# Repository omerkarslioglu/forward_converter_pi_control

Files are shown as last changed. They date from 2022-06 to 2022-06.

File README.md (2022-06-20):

# Forwar Converter With PI Controller
9-36V Input Voltage, 28 Output Voltage, All Ripple: %2, 50KHz, 50 Watt DC-DC Forward Converter Design And Production

The aim of the project is to design and produce a dc-dc forward converter according to following
requirements:
Vin: 36-9 V,
Vout: 28 V,
Power: 50 Watt,
Ripple Ratings: 2%,
Fsw : 50 KHz,
Control System: PI with a STM32F4 MCU.
In addition to this, this paper shows formulas, calculations, experimental and simulation results of dc-dc
forward converter.

# Forward Converter
A forward converter is a switched-mode power supply (SMPS) circuit that transfers energy to
secondary side from primary side and ensures to decrease secondary side input voltage. Forward
converter circuit is similar to the fly-back converter circuit but it is more efficient than fly-back
converter circuit. Forward converter is mainly used for the application which requires higher power
output.
Secondary side of forward converter basicly derives from buck converter. But forward converter can
increase or decrease the input voltage thanks to transformer.
Forward converter is an isolated circuit as it has transformer.



As per the above block diagram, when the switch is turned ON, the input is applied to the primary
winding of the transformer and a voltage is appeared at the secondary winding of transformer.
Therefore, the dot polarity of the windings of transformer is positive, due to this the diode D1 gets
forward biased. Then the output voltage of the transformer is fed to the low pass filter circuit which is
connected to the load. When switch is turned OFF, the current in the windings of transformer comes
down to zero (assuming the transformer to be ideal).
A typical forward converter consists of a:
 Transformer which is either a step-up or step-down with a single or multiple secondary
windings. The type used depends on the available input voltage and desired output voltage. It
also provides isolation of the load from the input voltage.
- Switching components
- Diodes
- Capacitors
- Inductor

# Circuit Design For Simulation On Simulink


The all calculations, values and simulations result in the report.

# Circuit Schematic


# PCB Design



# About Software
As it is known, this designed circuit is designed as a close loop system and will be controlled by
PI. The software of this circuit works as follows: voltage is read with ADC and required ratio
calculation is made. This calculated value enters the PI algorithm and is compared with the
setpoint. If this value is not the same as the setpoint, the PI calculates a new value close to or the
same as the setpoint. This value is again proportioned and the PWM signal driving the mosfet is
updated again.


The closed loop system of Forward Converter is as above diagram. It is PID system. But Kd equals 0
as seting PI.
The software generally consists of two or three main modules:
1. main.c : It is the file where all the configurations are found, the main algorithm and PWM are
set.
2. ADC_READ.c : It is an analog reading value module that I developed specially for the
STM32F4 discovery board.
3. PID.c : It is the module where I wrote the PID algorithm.
Other folders belong to the HAL Library used and the processor's drivers.



All necessary explanations are in the software modules in the software folder in the project file.

Product:
WhatsApp Image 2022-06-20 at 11 33 35
WhatsApp Image 2022-06-20 at 11 33 34

If you have any question, you can contact me.

Omer Karslioglu
omerkarsliogluu@gmail.com

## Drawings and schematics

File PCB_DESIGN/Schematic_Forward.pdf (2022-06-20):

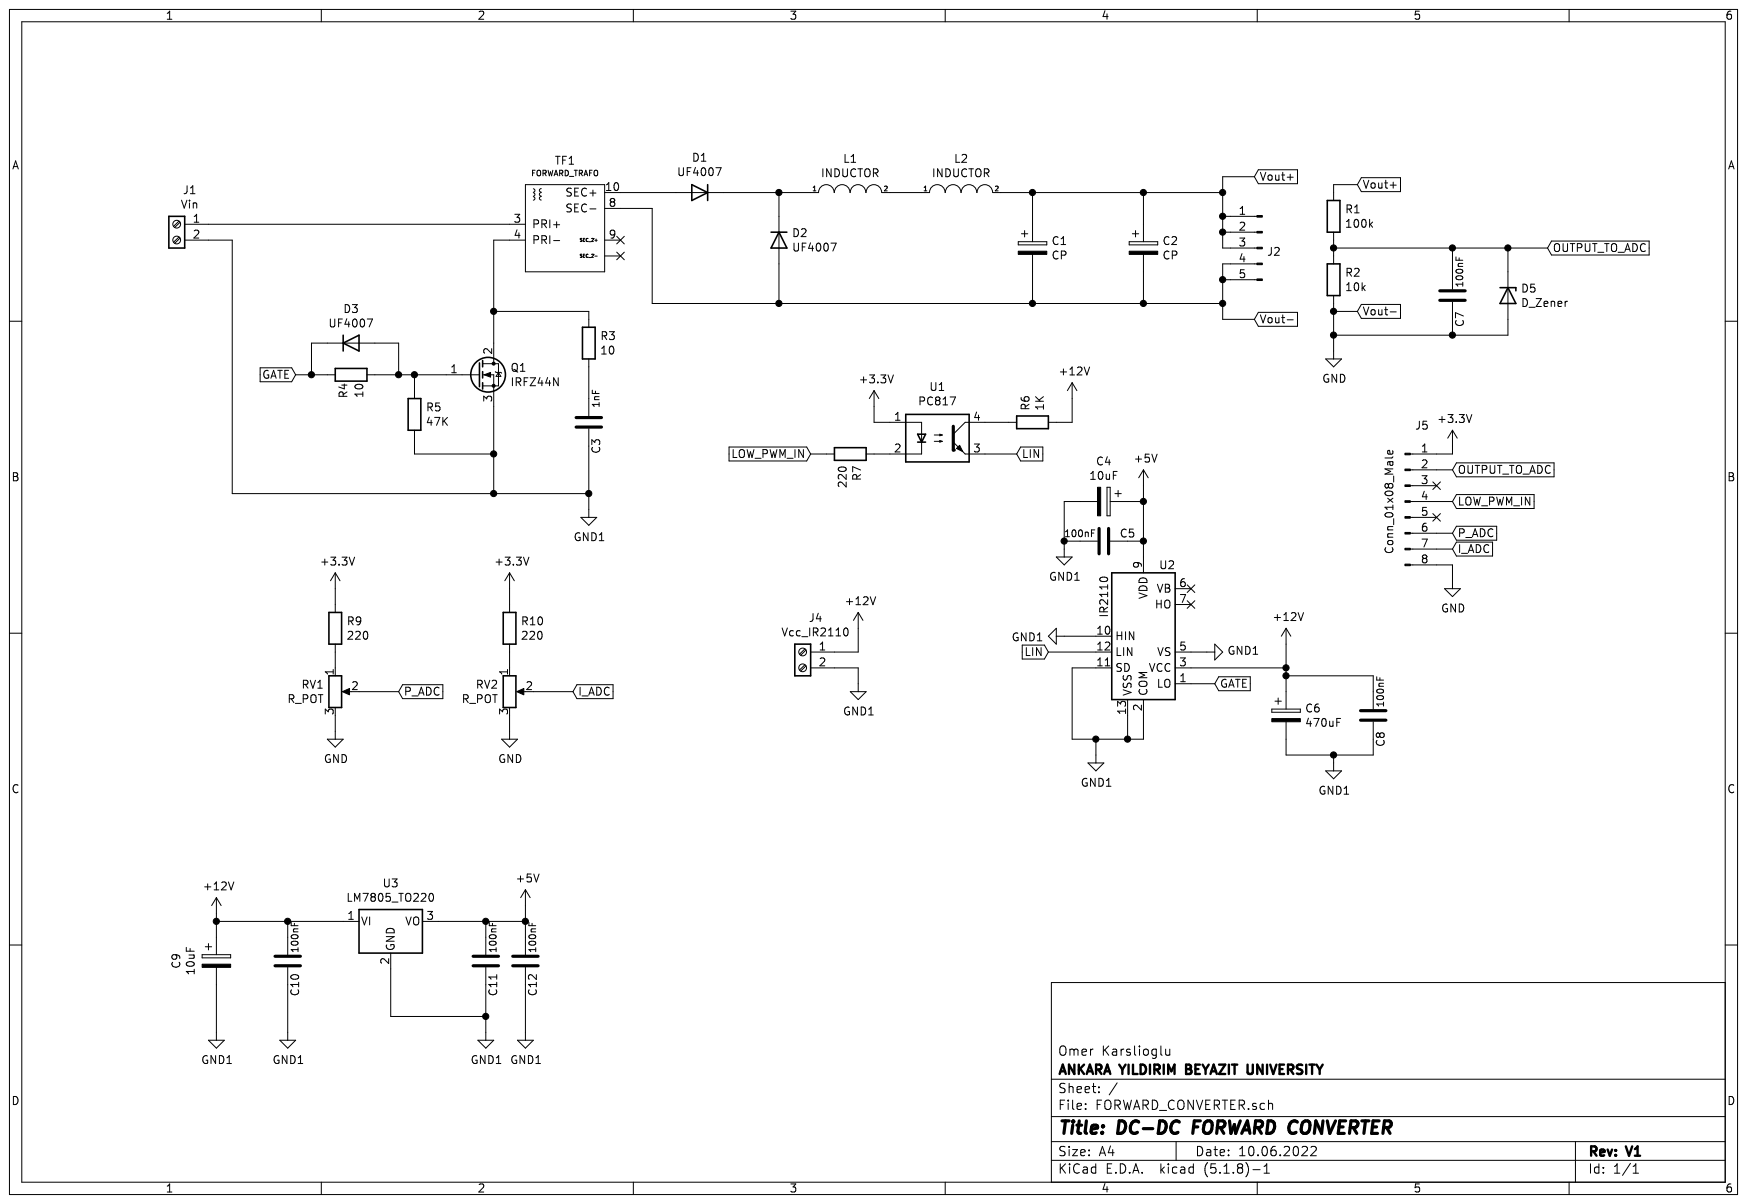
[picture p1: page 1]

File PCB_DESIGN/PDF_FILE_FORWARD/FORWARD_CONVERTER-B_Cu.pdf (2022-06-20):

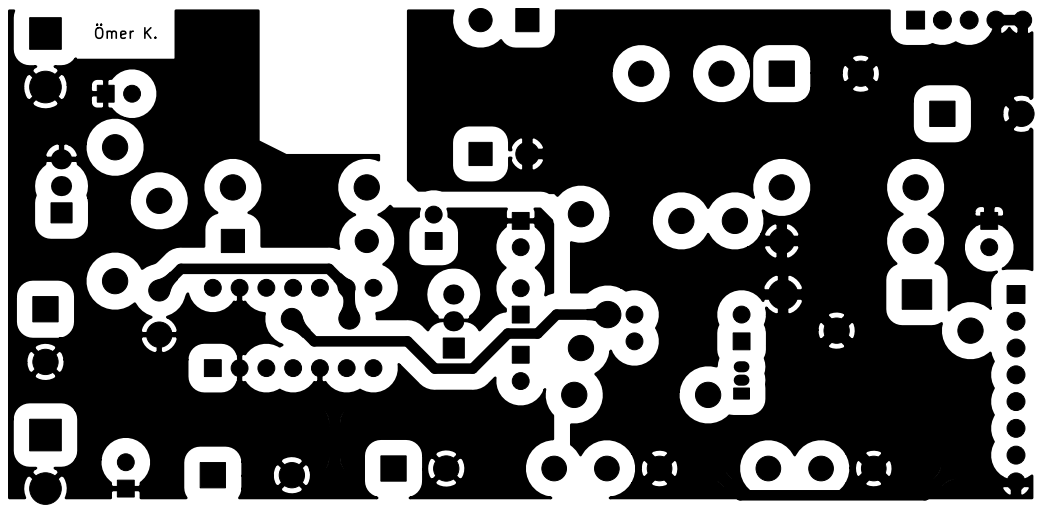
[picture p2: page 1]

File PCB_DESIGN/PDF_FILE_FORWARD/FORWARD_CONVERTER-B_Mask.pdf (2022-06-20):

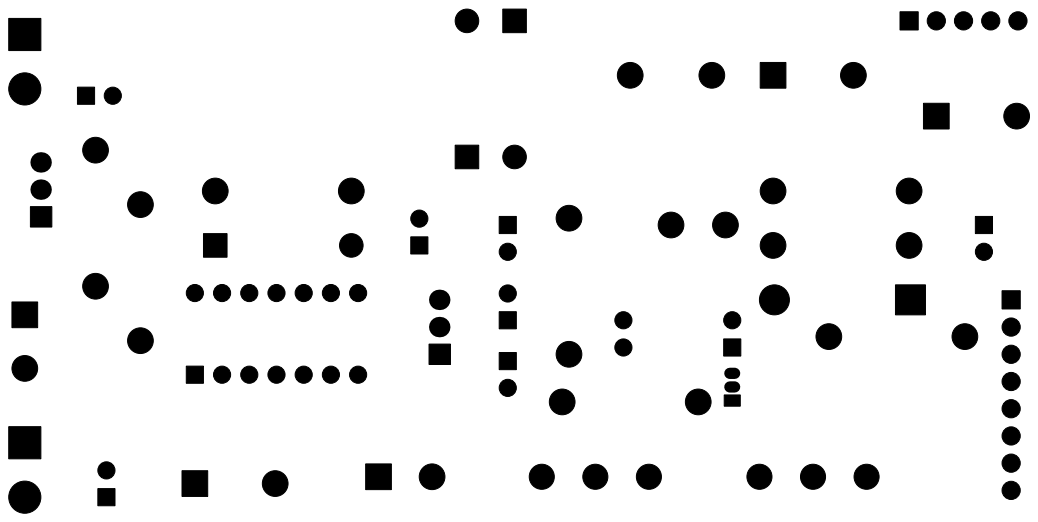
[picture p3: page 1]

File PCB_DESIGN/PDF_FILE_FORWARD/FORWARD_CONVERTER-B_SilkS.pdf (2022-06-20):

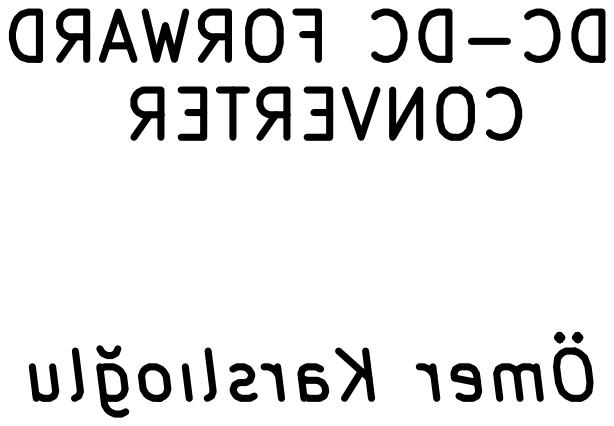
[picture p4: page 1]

Ömer Karslolu DC-DC FORWARD

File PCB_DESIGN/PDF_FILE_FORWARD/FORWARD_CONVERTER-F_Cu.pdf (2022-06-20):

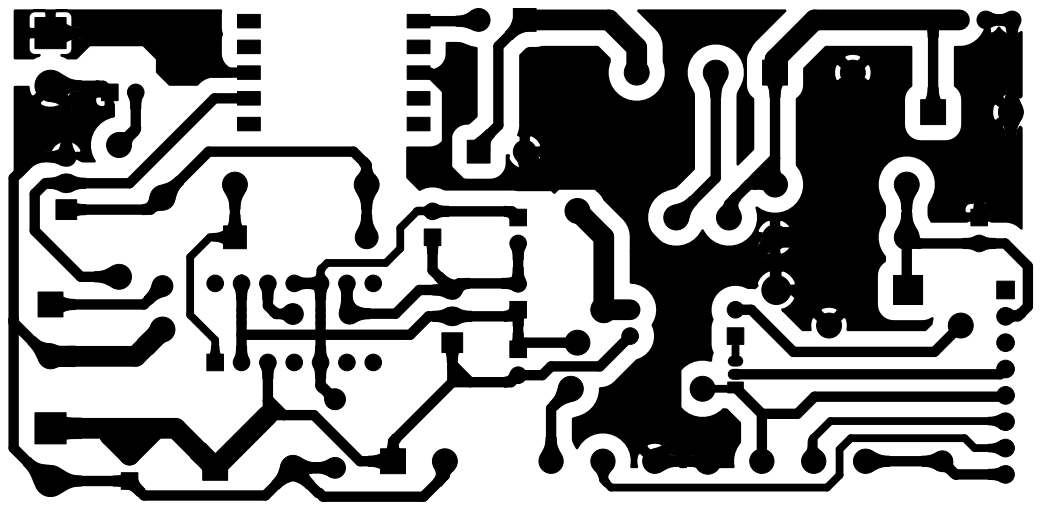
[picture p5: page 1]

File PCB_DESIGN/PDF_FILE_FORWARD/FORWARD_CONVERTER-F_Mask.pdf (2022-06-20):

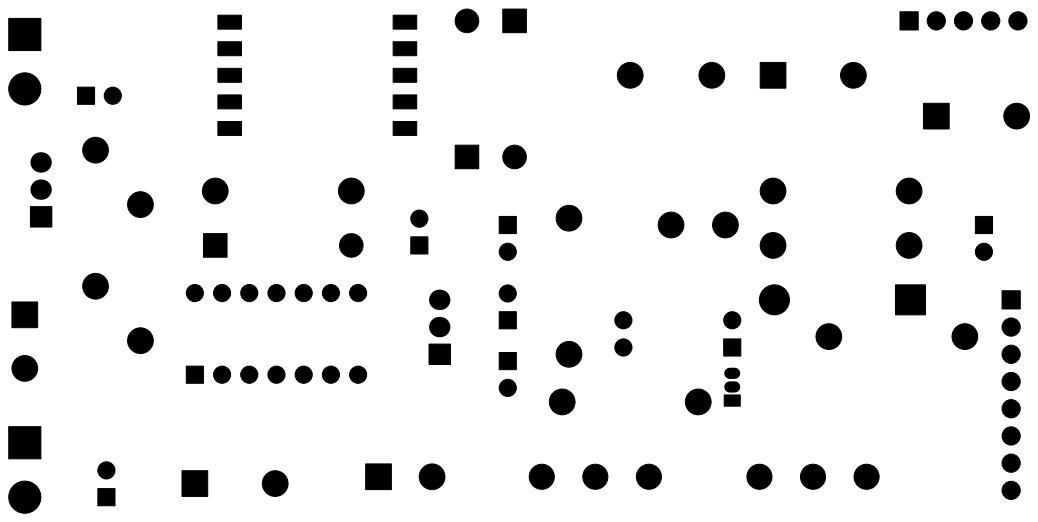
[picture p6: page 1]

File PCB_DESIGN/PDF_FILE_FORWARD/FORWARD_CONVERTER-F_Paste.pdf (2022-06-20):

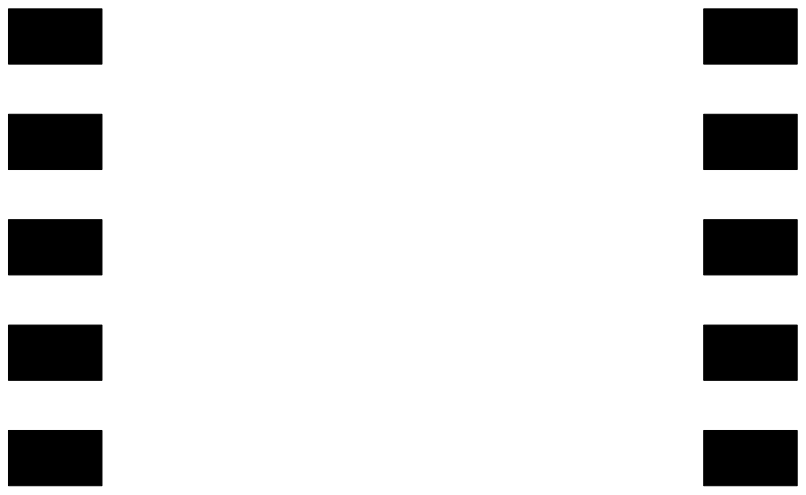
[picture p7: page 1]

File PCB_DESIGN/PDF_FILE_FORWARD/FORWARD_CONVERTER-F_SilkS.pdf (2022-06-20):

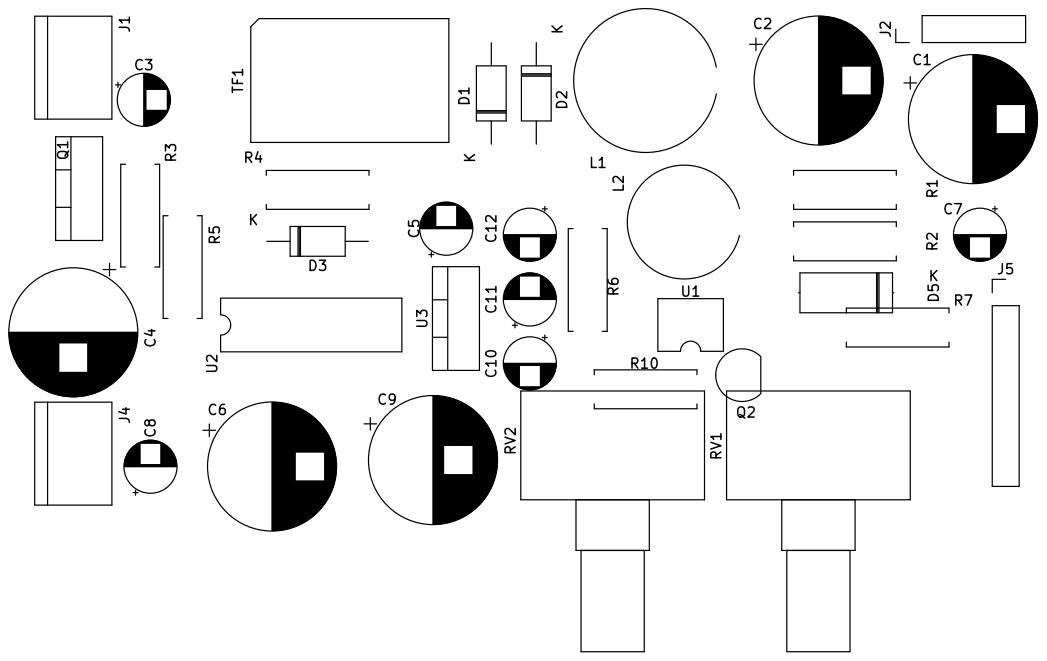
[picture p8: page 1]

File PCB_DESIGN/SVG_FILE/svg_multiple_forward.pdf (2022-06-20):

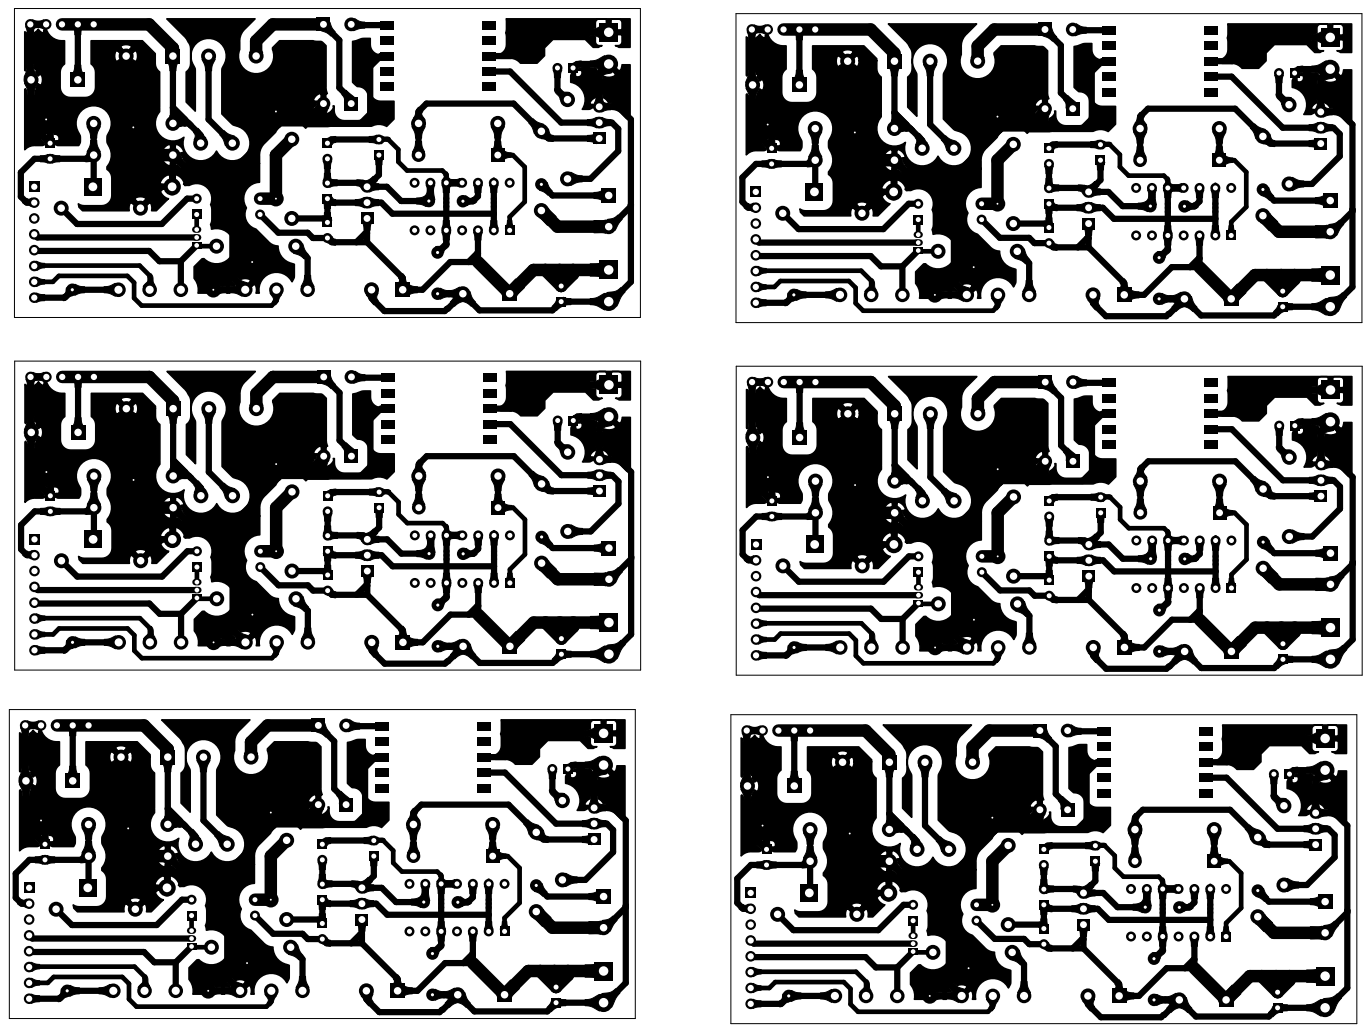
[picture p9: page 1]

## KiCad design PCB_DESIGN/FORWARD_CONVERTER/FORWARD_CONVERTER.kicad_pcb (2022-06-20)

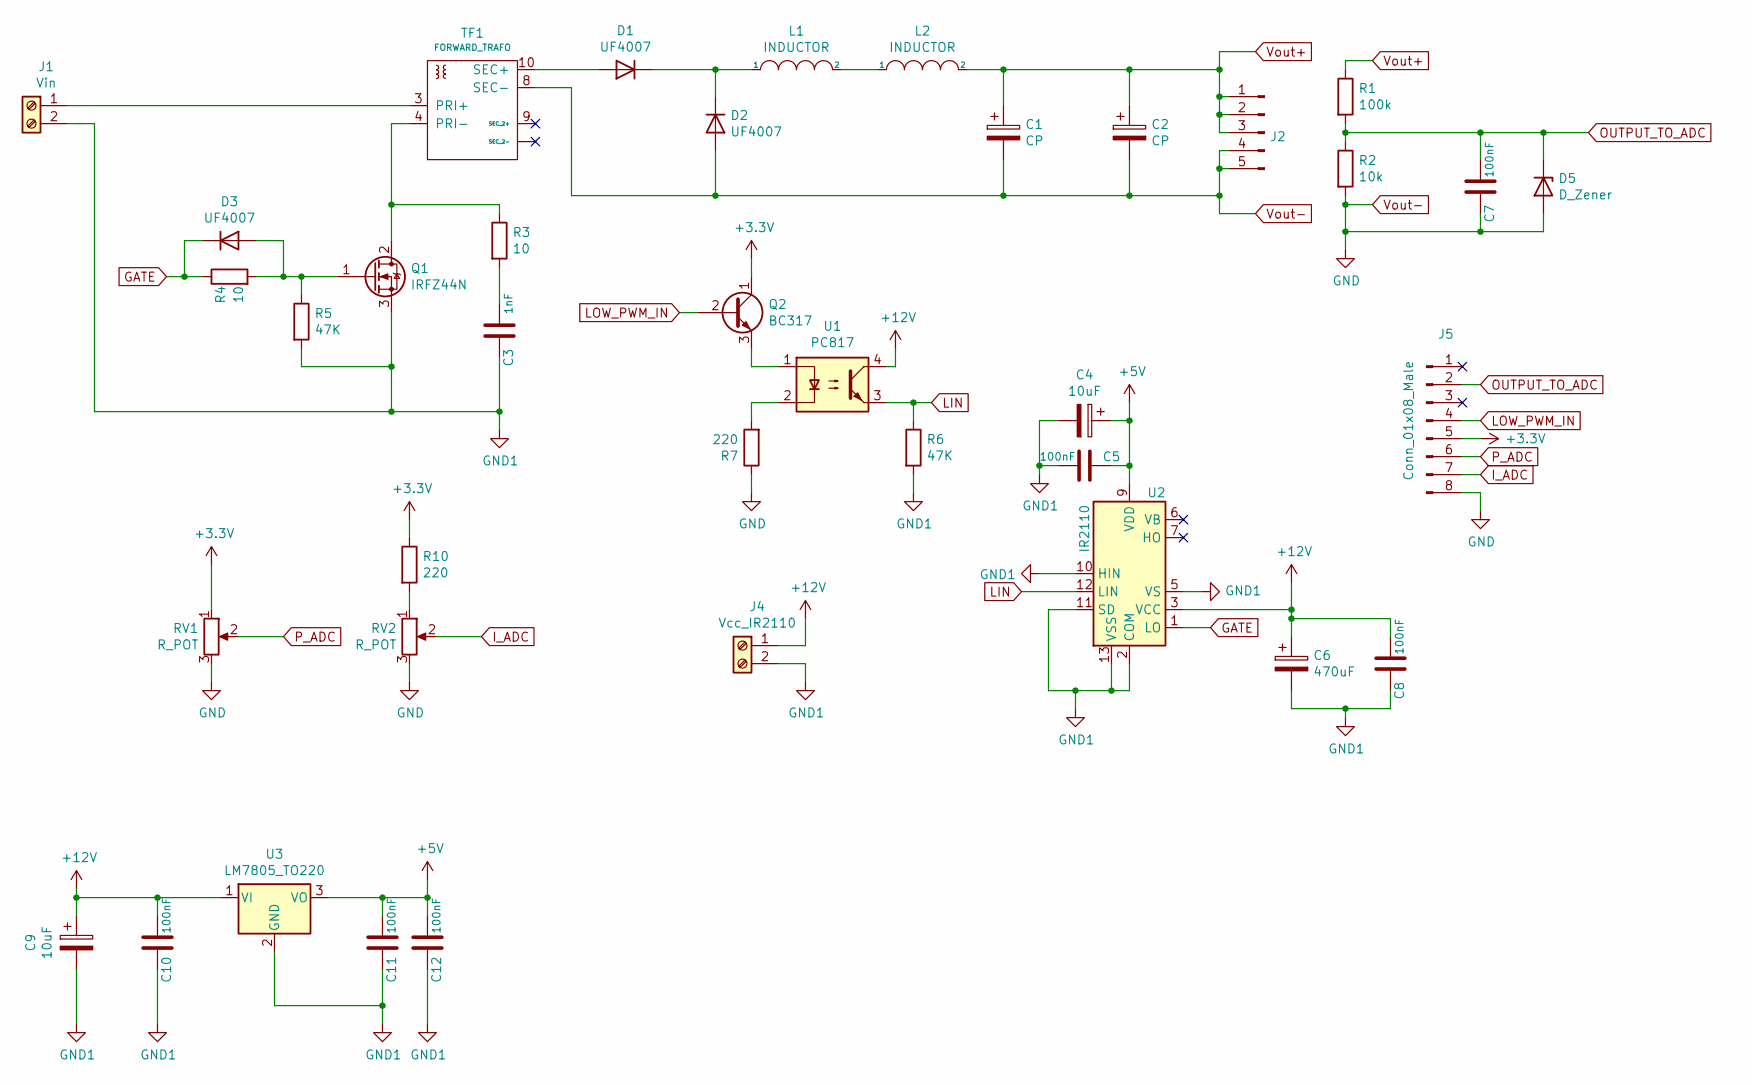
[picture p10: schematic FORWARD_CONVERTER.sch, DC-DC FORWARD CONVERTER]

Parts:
C1, C2: CP; CP_Radial_D12.5mm_P7.50mm
C3: 1nF; CP_Radial_D5.0mm_P2.50mm
C4, C9: 10uF; CP_Radial_D12.5mm_P5.00mm
C5, C7, C8, C10, C11, C12: 100nF; CP_Radial_D5.0mm_P2.50mm
C6: 470uF; CP_Radial_D12.5mm_P7.50mm
D1, D2, D3: UF4007; D_DO-41_SOD81_P12.70mm_Horizontal
D5: D_Zener; D_5W_P12.70mm_Horizontal
J1: Vin; TerminalBlock_bornier-2_P5.08mm
J2: Conn_01x05_Male; PinHeader_1x05_P2.54mm_Vertical
J4: Vcc_IR2110; TerminalBlock_bornier-2_P5.08mm
J5: Conn_01x08_Male; PinHeader_1x08_P2.54mm_Vertical
L1: INDUCTOR; L_Axial_L26.7mm_D14.0mm_P7.62mm_Vertical_Vishay_IHA-104
L2: INDUCTOR; L_Axial_L26.0mm_D11.0mm_P5.08mm_Vertical_Fastron_77A
Q1: IRFZ44N; TO-220-3_Vertical
Q2: BC317; TO-92_Inline
R1: 100k; R_Axial_DIN0411_L9.9mm_D3.6mm_P12.70mm_Horizontal
R2: 10k; R_Axial_DIN0411_L9.9mm_D3.6mm_P12.70mm_Horizontal
R3, R4: 10; R_Axial_DIN0411_L9.9mm_D3.6mm_P12.70mm_Horizontal
R5, R6: 47K; R_Axial_DIN0411_L9.9mm_D3.6mm_P12.70mm_Horizontal
R7, R10: 220; R_Axial_DIN0411_L9.9mm_D3.6mm_P12.70mm_Horizontal
RV1, RV2: R_POT; Potentiometer_Alps_RK163_Single_Horizontal
TF1: FORWARD_TRAFO
U1: PC817; DIP-4_W10.16mm
U2: IR2110; DIP-14_W7.62mm
U3: LM7805_TO220; TO-220-3_Vertical

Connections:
+3V3: J5.5, Q2.1 (C), R10.1, RV1.1
+5V: C4.1, C5.1, C11.2, C12.2, U2.9 (VDD), U3.3 (VO)
+12V: C6.1, C8.2, C9.1, C10.2, J4.1, U1.4, U2.3 (VCC), U3.1 (VI)
GATE: D3.1 (K), R4.1, U2.1 (LO)
GND1: C3.1, C4.2, C5.2, C6.2, C8.1, C9.2, C10.1, C11.1, C12.1, J1.2, J4.2, Q1.3 (S), R5.2, R6.2, U2.2 (COM), U2.5 (VS), U2.10 (HIN), U2.11 (SD), U2.13 (VSS), U3.2 (GND)
I_ADC: J5.7, RV2.2
LIN: R6.1, U1.3, U2.12 (LIN)
LOW_PWM_IN: J5.4, Q2.2 (B)
unnamed: C3.2, R3.2
unnamed: D1.1 (K), D2.1 (K), L1.1
unnamed: D1.2 (A), TF1.10 (SEC+)
unnamed: D3.2 (A), Q1.1 (G), R4.2, R5.1
unnamed: J1.1, TF1.3 (PRI+)
unnamed: L1.2, L2.1
unnamed: Q1.2 (D), R3.1, TF1.4 (PRI-)
unnamed: Q2.3 (E), U1.1
unnamed: R7.2, U1.2
unnamed: R10.2, RV2.1
OUTPUT_TO_ADC: C7.2, D5.1 (K), J5.2, R1.2, R2.1
P_ADC: J5.6, RV1.2
Vout+: C1.1, C2.1, J2.1, J2.2, J2.3, L2.2, R1.1
Vout-: C1.2, C2.2, C7.1, D2.2 (A), D5.2 (A), J2.4, J2.5, J5.8, R2.2, R7.1, RV1.3, RV2.3, TF1.8 (SEC-)

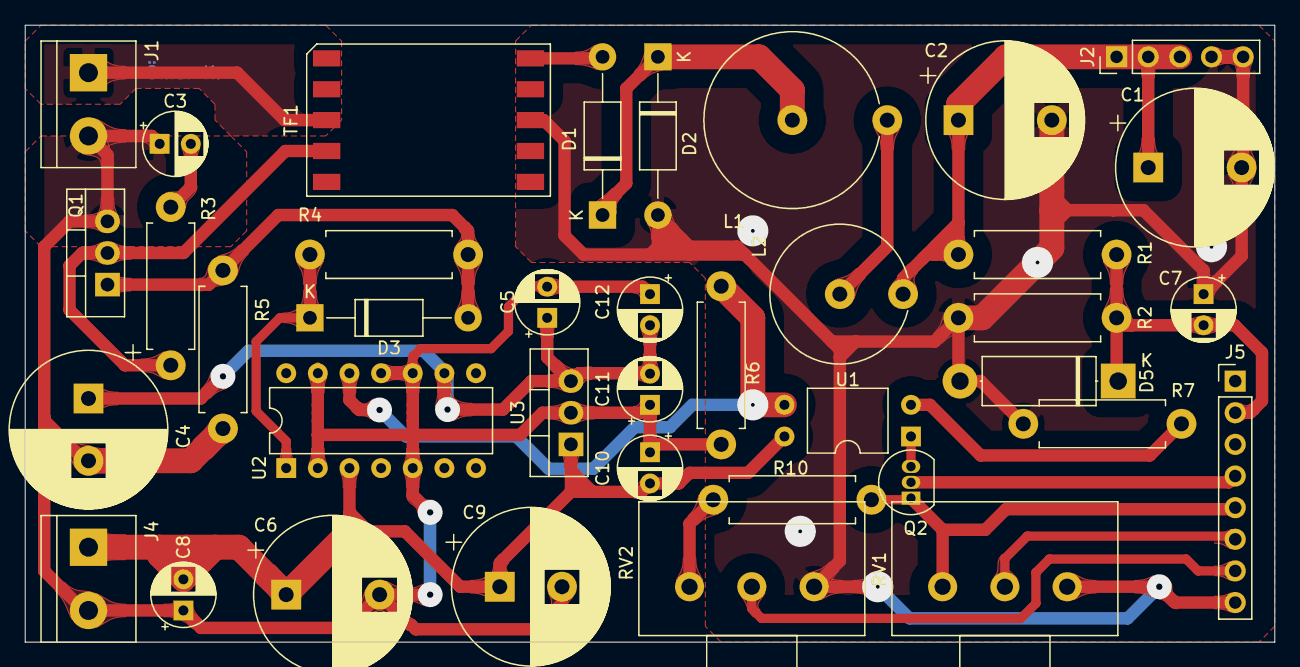
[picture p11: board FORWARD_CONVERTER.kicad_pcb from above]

Board: 2 copper layers, 100.3 x 49.5 mm, 38 parts (0 on the bottom side), 22 nets.

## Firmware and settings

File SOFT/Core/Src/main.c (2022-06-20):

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
/* Includes ------------------------------------------------------------------*/
#include "main.h"

/* USER CODE BEGIN Includes */
#include <stdio.h>
#include <stdlib.h>
#include "ADC_READ.h"
#include "PID.h"
/* USER CODE END Includes */

/* USER CODE BEGIN PD */

#define MIN_PWM_DUTY (float) (7.8  - 4.0)  //(PERCENT RATIO) -> 28/360
#define MAX_PWM_DUTY (float) (31.0 + 4.0)  //(PERCENT RATIO) -> 28/90
#define pwm_resolution (uint16_t) (420-1)
#define adc_resolution (uint16_t) (1024-1)

#define max_lim_integral 10.0f

#define max_lim_PID 30.0f

#define k_p 1.0f
#define k_i 7.0f

/* USER CODE END PD */

ADC_HandleTypeDef hadc1;

TIM_HandleTypeDef htim1;

/* USER CODE BEGIN PV */

uint16_t measurement=0;
float p_constant=0.0;
float i_constant=0.0;

uint16_t min_pwm = 0;
uint16_t max_pwm = 0;
float set_point = 0;

uint16_t 	sim_pwm_out=0;
uint16_t  sim_measurement=0;

uint16_t pwm=0;

float PID_out;
//double kp=0, ki=0, kd=0;
//float pid_p=0, pid_i=0, pid_d=0, PID;
//float error, previousError;
//unsigned long t_now, t_last, dt;

/* USER CODE END PV */

void SystemClock_Config(void);
static void MX_GPIO_Init(void);
static void MX_ADC1_Init(void);
static void MX_TIM1_Init(void);
/**
  * @brief  The application entry point.
  * @retval int
  */
int main(void)
{
  /* USER CODE BEGIN 1 */

	//uint16_t pwm_resolution_int_buff = pwm_resolution;

  /* USER CODE END 1 */

  /* MCU Configuration--------------------------------------------------------*/

  /* Reset of all peripherals, Initializes the Flash interface and the Systick. */
  HAL_Init();

  /* Configure the system clock */
  SystemClock_Config();

  /* Initialize all configured peripherals */
  MX_GPIO_Init();
  MX_ADC1_Init();
  MX_TIM1_Init();
  /* USER CODE BEGIN 2 */

  TIM1->CCR1 = 0; // (MAX: 420)
  HAL_TIM_PWM_Start(&htim1, TIM_CHANNEL_1);

//  HAL_TIM_PWM_Start_DMA(&htim1, TIM_CHANNEL_1, pwm_value, 10);

  for(int i=0; i<2; i++)
  {
	  min_pwm = 0;//(MIN_PWM_DUTY/100.0)*pwm_resolution;
	  max_pwm = (MAX_PWM_DUTY/100.0)*pwm_resolution;
	  set_point = (2.54/3.3)*adc_resolution-20; // for 28v => (2.54/3.3)*(resolution-1)
  }

  PIDController pid = {k_p, k_i, max_lim_integral, max_lim_PID};

  PIDController_Init(&pid);

  /* USER CODE END 2 */

  /* Infinite loop */
  /* USER CODE BEGIN WHILE */
  while(1)
  {
	  ADC_Select_CH0();
	  HAL_ADC_Start(&hadc1);
	  HAL_ADC_PollForConversion(&hadc1, 1000);
	  measurement = HAL_ADC_GetValue(&hadc1);
	  HAL_ADC_Stop(&hadc1);

	  ADC_Select_CH1();
	  HAL_ADC_Start(&hadc1);
	  HAL_ADC_PollForConversion(&hadc1, 1000);
	  p_constant = (HAL_ADC_GetValue(&hadc1)/10); // P constant
	  HAL_ADC_Stop(&hadc1);

	  ADC_Select_CH2();
	  HAL_ADC_Start(&hadc1);
	  HAL_ADC_PollForConversion(&hadc1, 1000);
	  i_constant = (HAL_ADC_GetValue(&hadc1)/10); // I constant
	  HAL_ADC_Stop(&hadc1);

	  PIDController pid = {p_constant, i_constant, max_lim_integral, max_lim_PID};

	  //Set pwm:
	  PID_out = PIDController_Update(&pid, set_point, measurement, pwm_resolution, adc_resolution);
	  pwm = pwm-PID_out;

	  if(pwm<min_pwm)
		  pwm = min_pwm;
	  else if(pwm>max_pwm)
		  pwm = max_pwm;



	  TIM1->CCR1 = pwm; //*****************************************

	  HAL_Delay(10);

//	  sim_pwm_out = (pwm/pwm_resolution)*100;
//	  sim_measurement = (measurement/adc_resolution)*100;
  }
    /* USER CODE END WHILE */

}

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


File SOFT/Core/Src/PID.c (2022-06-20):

/*
* Designed by Omer Karslioglu
* PID algorithm (just used PI)
*/

#include "PID.h"

void PIDController_Init(PIDController *pid) {

	/* Clear controller variables */
	pid->pid_p	= 0.0f;
	pid->pid_i	= 0.0f;

	pid->error	= 0.0f;

	pid->PID = 0.0f;

	pid->previousError = 0.0f;
}

float PIDController_Update(PIDController *pid, float setpoint, int measurement, int pwm_resolution, int adc_resolution) {

	/*
	* Error signal
	*/
    pid->error = -setpoint+measurement;


	/*
	* Proportional
	*/
    pid->pid_p = pid->kp*pid->error;


	//integrator:
	if(-10<pid->error && pid->error<10)
	{
		pid->pid_i=pid->pid_i+(pid->ki*pid->error);
		// anti wind-up
		if(pid->pid_i>pid->max_lim_integral)
			pid->pid_i=pid->max_lim_integral;
		else if(pid->pid_i<-pid->max_lim_integral)
			pid->pid_i=-pid->max_lim_integral;
	}

	// Derivator
	//pid_d=kd*((error-previousError)/dt);


	/*
	* Compute output and apply limits
	*/
	//PID out:
	pid->PID=((pid->pid_p+pid->pid_i)*pwm_resolution)/adc_resolution;

	//PID limit:
	if(pid->PID<-pid->max_lim_PID)
	{
	  pid->PID=-pid->max_lim_PID;
	}
	if(pid->PID>pid->max_lim_PID)
	{
	  pid->PID=pid->max_lim_PID;
	}

	/* Store error and measurement for later use */
    pid->previousError = pid->error;

	/* Return controller output */
    return pid->PID;
}

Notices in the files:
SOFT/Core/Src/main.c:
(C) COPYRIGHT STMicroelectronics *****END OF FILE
